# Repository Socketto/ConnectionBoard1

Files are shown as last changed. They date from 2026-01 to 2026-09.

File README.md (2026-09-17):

# RS-485 Multi-Socket Board

## Overview

This project describes a **simple RS-485 interface board** designed to allow communication between devices using **different cable types and connectors**.

The board acts as a passive/low-complexity hub, exposing multiple RS-485 connectors while keeping the electrical interface consistent. It is intended for prototyping, testing, field wiring adaptation, and small installations where flexibility is more important than protocol conversion.

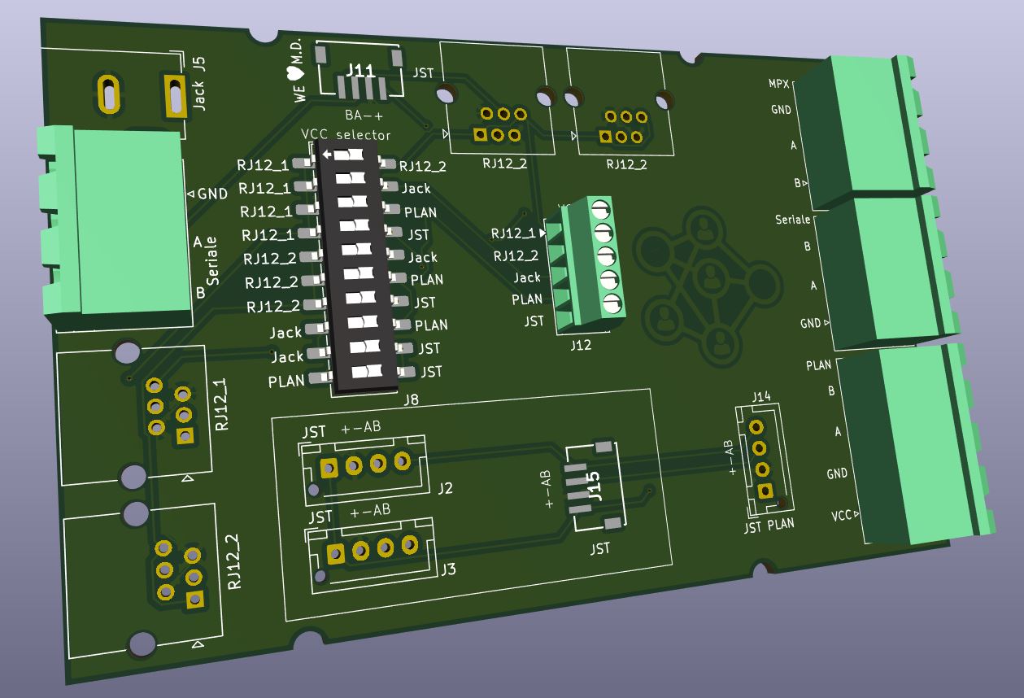
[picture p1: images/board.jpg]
Board
  

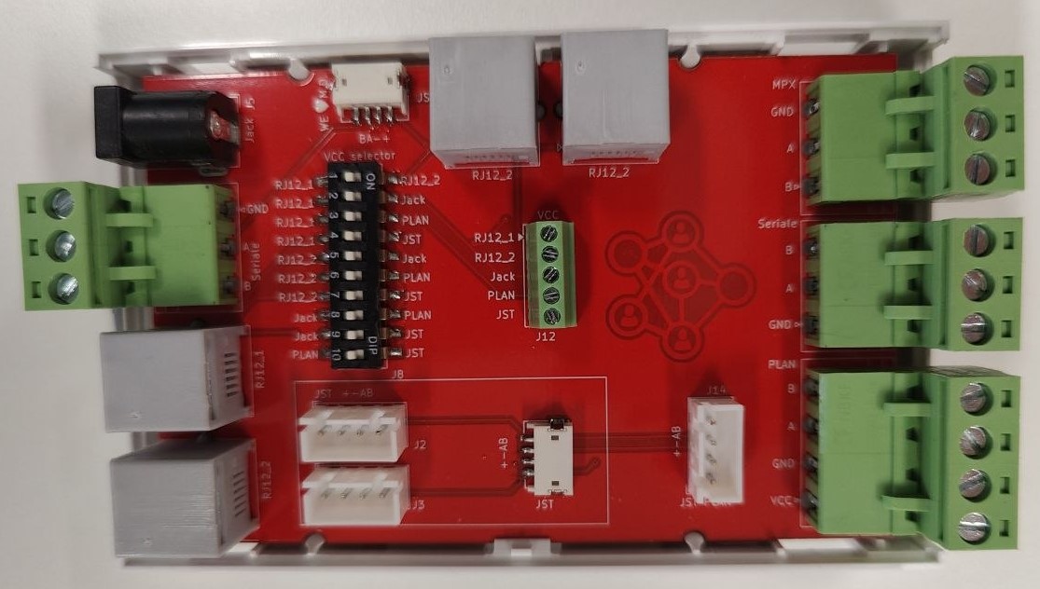
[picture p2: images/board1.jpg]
Board


## Features

* Multiple connectors for RS-485 communication
* Designed to support **different cable types** on the same board
* Common RS-485 differential bus (A/B)
* Simple and robust hardware design
* No active logic required for basic operation

## Power Distribution

The board includes a **10-pin selector (jumper-based or switch-based, depending on implementation)** that allows flexible routing of the **VCC line**.

Using this selector, VCC can be:

* Routed to one or more RS-485 connectors
* Isolated from specific connectors if required
* Connected to the external power input

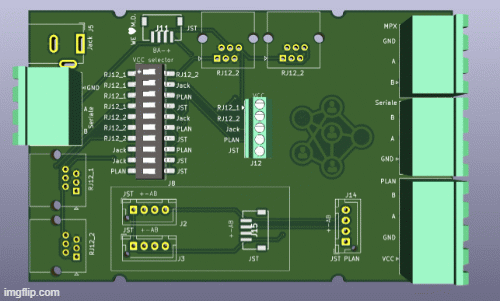
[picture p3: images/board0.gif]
Board


This makes it possible to power connected devices directly from the board or keep power lines separated, depending on the application.

## External Power Input

An external power supply can be connected using a **standard 5 mm DC barrel jack**.

* Typical use: powering the RS-485 bus or connected devices
* The external VCC can be selectively distributed via the 10-pin selector
* Ground is shared across all connectors

> ⚠️ **Note:** Ensure that voltage and current ratings are compatible with all connected devices before enabling VCC routing.

## Typical Use Cases

* RS-485 device testing and debugging
* Adapting different connector standards to a single RS-485 bus
* Rapid prototyping of industrial or home automation networks
* Field wiring where multiple cable types must coexist

## Project Status

This is a **simple hardware project**, intended to be easy to understand, modify, and manufacture. It can be extended with:

* Termination resistors
* Biasing resistors
* Protection components (TVS, fuses)
* Optional active transceivers

## License

This project is released under an open-source license. See the `LICENSE` file for details.

---

If you build or modify this board, contributions and improvements are welcome.

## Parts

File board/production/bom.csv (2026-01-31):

Designator | Footprint | Quantity | Value | LCSC Part #
J1, J13, J16, J4 | RJ25_Wayconn_MJEA-660X1_Horizontal | 4 | RJ12
J10 | PhoenixContact_MSTBA_2,5_4-G-5,08_1x04_P5.08mm_Horizontal | 1 | PLAN
J11, J15 | 648104131822 | 2 | REMOTE_DISPLAY
J12 | TerminalBlock_Phoenix_MPT-0,5-5-2.54_1x05_P2.54mm_Horizontal | 1 | Conn_01x05_Socket
J14 | JST_XH_B4B-XH-AM_1x04_P2.50mm_Vertical | 1 | JST PLAN
J2, J3 | JST_XH_B4B-XH-AM_1x04_P2.50mm_Vertical | 2 | JST XH
J5 | BarrelJack_GCT_DCJ200-10-A_Horizontal | 1 | Barrel_Jack
J6, J9 | PhoenixContact_MSTBA_2,5_3-G_1x03_P5.00mm_Horizontal | 2 | Seriale
J7 | PhoenixContact_MSTBA_2,5_3-G_1x03_P5.00mm_Horizontal | 1 | MPX
J8 | SW_DIP_SPSTx10_Slide_6.7x26.96mm_W8.61mm_P2.54mm_LowProfile | 1 | Conn_02x10_Counter_Clockwise_MountingPin

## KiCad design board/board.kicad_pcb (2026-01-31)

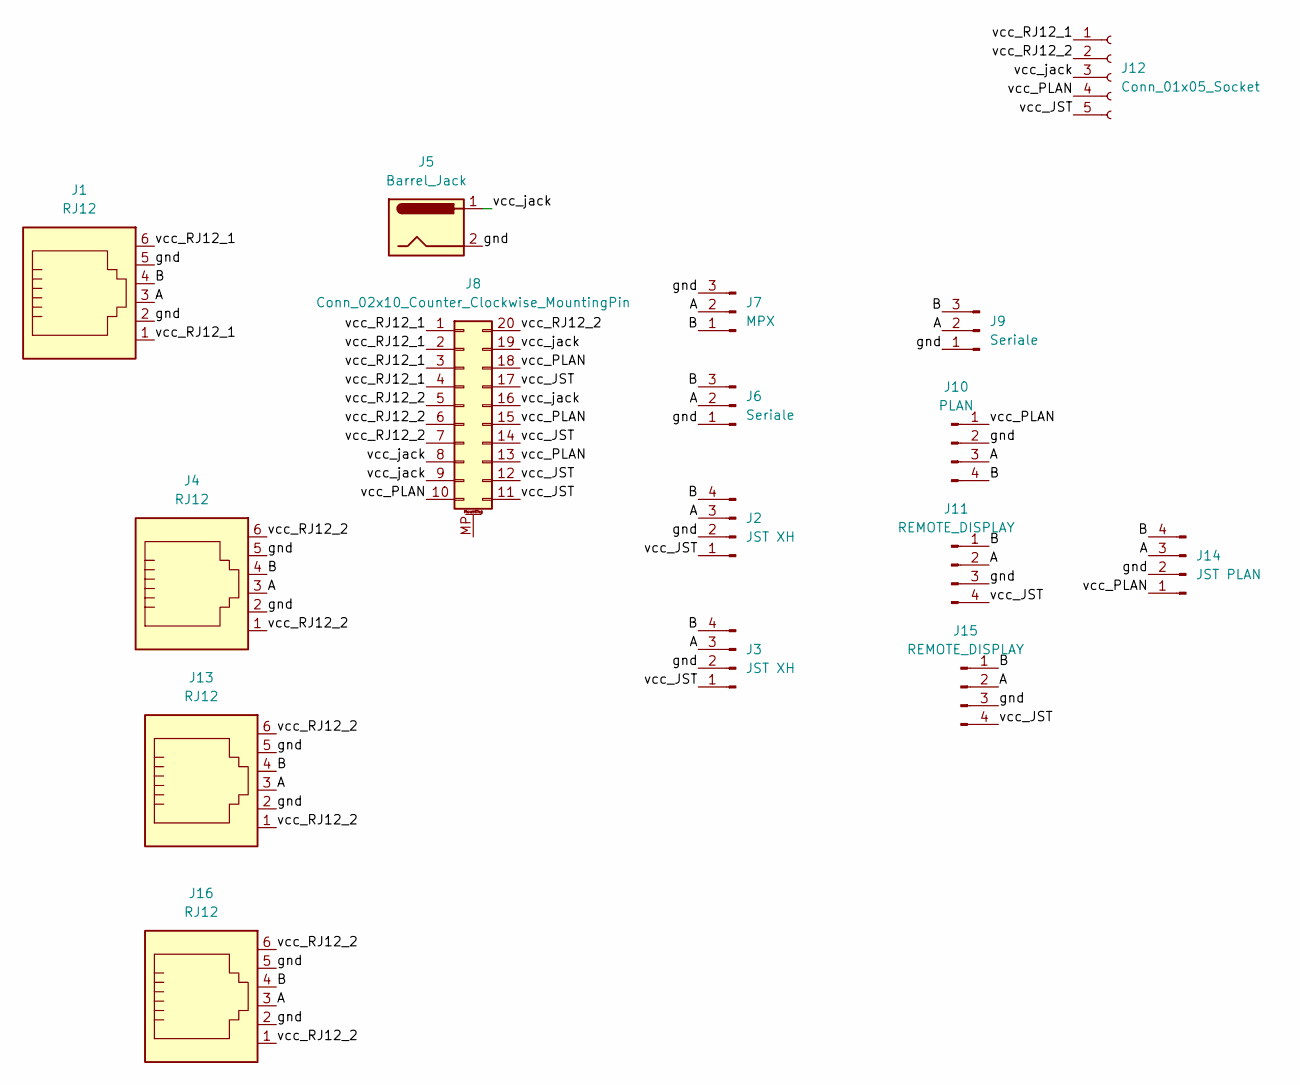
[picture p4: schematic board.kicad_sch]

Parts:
J1, J4, J13, J16: RJ12; RJ25_Wayconn_MJEA-660X1_Horizontal
J2, J3: JST XH; JST_XH_B4B-XH-AM_1x04_P2.50mm_Vertical
J5: Barrel_Jack; BarrelJack_GCT_DCJ200-10-A_Horizontal
J6, J9: Seriale; PhoenixContact_MSTBA_2,5_3-G_1x03_P5.00mm_Horizontal
J7: MPX; PhoenixContact_MSTBA_2,5_3-G_1x03_P5.00mm_Horizontal
J8: Conn_02x10_Counter_Clockwise_MountingPin; SW_DIP_SPSTx10_Slide_6.7x26.96mm_W8.61mm_P2.54mm_LowProfile
J10: PLAN; PhoenixContact_MSTBA_2,5_4-G-5,08_1x04_P5.08mm_Horizontal
J11, J15: REMOTE_DISPLAY; 648104131822
J12: Conn_01x05_Socket; TerminalBlock_Phoenix_MPT-0,5-5-2.54_1x05_P2.54mm_Horizontal
J14: JST PLAN; JST_XH_B4B-XH-AM_1x04_P2.50mm_Vertical

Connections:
/A: J1.3, J2.3, J3.3, J4.3, J6.2, J7.2, J9.2, J10.3, J11.2, J13.3, J14.3, J15.2, J16.3
/B: J1.4, J2.4, J3.4, J4.4, J6.3, J7.1, J9.3, J10.4, J11.1, J13.4, J14.4, J15.1, J16.4
/gnd: J1.2, J1.5, J2.2, J3.2, J4.2, J4.5, J5.2, J6.1, J7.3, J9.1, J10.2, J11.3, J13.2, J13.5, J14.2, J15.3, J16.2, J16.5
/vcc_JST: J2.1, J3.1, J8.11, J8.12, J8.14, J8.17, J11.4, J12.5, J15.4
/vcc_PLAN: J8.10, J8.13, J8.15, J8.18, J10.1, J12.4, J14.1
/vcc_RJ12_1: J1.1, J1.6, J8.1, J8.2, J8.3, J8.4, J12.1
/vcc_RJ12_2: J4.1, J4.6, J8.5, J8.6, J8.7, J8.20, J12.2, J13.1, J13.6, J16.1, J16.6
/vcc_jack: J5.1, J8.8, J8.9, J8.16, J8.19, J12.3

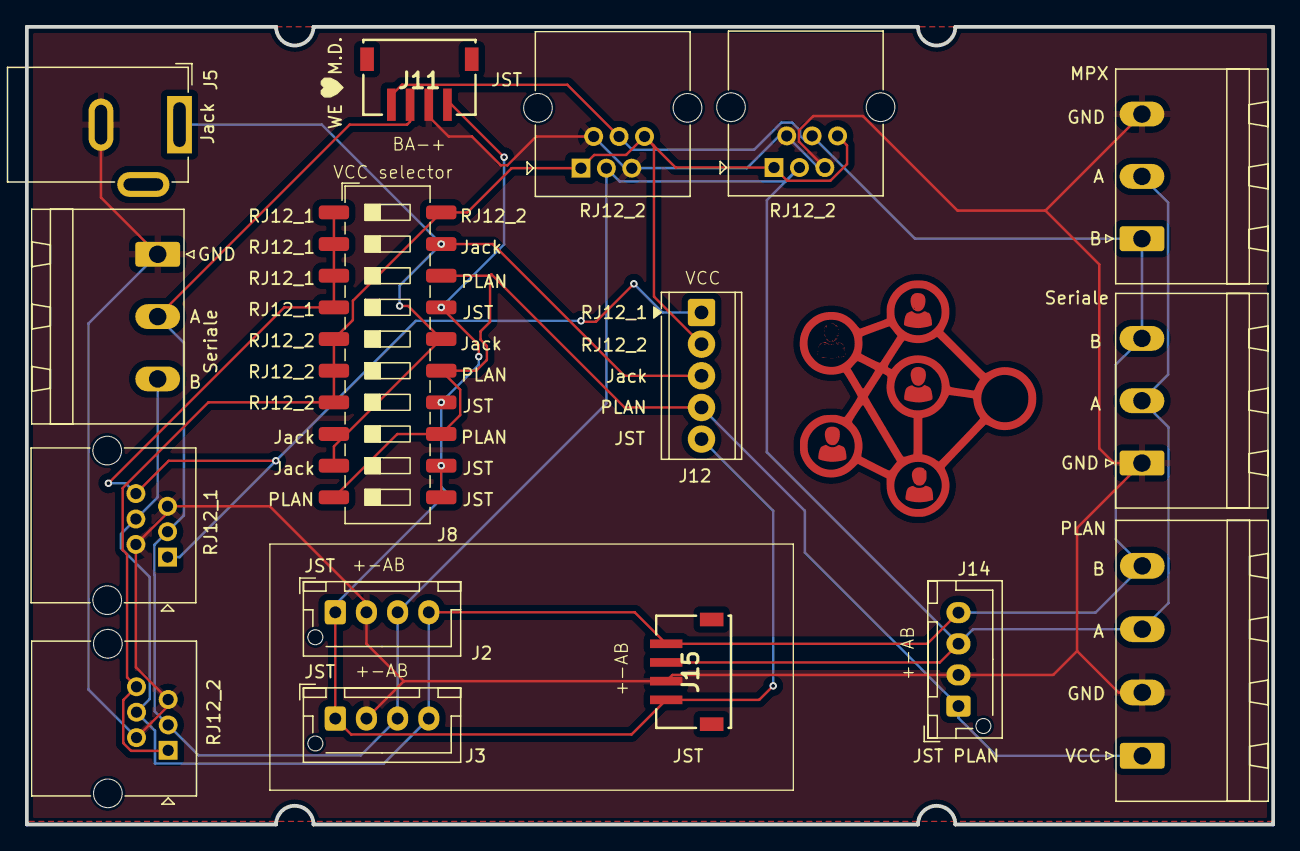
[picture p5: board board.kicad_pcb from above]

Board: 2 copper layers, 100.0 x 64.0 mm, 16 parts (0 on the bottom side), 8 nets.

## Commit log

2026-01-29 [FIX] First commit
    [board.kicad_pcb, board.kicad_sch, bom.csv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]
2026-01-29 [UPD] Update readme with image of board
2026-01-30 [ADD] Add new sockets
    [board.kicad_pcb, board.kicad_sch, bom.csv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]
2026-01-30 [UPD] Update image
    [board.kicad_pcb]
2026-01-31 [UPD] Final version for JLCPCB
    [board.kicad_pcb, board.kicad_sch, bom.csv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]
